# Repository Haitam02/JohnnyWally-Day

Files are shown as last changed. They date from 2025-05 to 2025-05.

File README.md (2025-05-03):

# 🤖 Eurobots 2025 – Embedded Systems Project

Welcome to the official repository for our participation in **Eurobots 2025**, part of the **Embedded Project** course.  
This project was developed by a team of six students:

- Ibrahim Zian  
- Samir Bouchrit  
- Haitam Lebatte  
- Soraya Jelti  
- Timothé Couturier  
- Yllke Prebreza  

---

## 🎮 Context: *The Show Must Go On*

This repository contains all the code used for the **Eurobots 2025** competition:  
**“The Show Must Go On”**

Each match lasts **100 seconds**.

- The **Big Robot** can start **immediately**. To score points, it must:
  - **Deploy a banner**
  - **Reach its final zone** before the match ends

- The **Pamis** and the **Superstar** can only start from the **85th second**.
  - The **Pamis** must move to one of the **three target zones** in front of the stage.
  - The **Superstar** must **climb the stage** and advance **as far as possible**.

- After 100 seconds, **all robots must stop** automatically.

---

## 🎯 Project Goal

The goal of the project was to design and build multiple coordinated robots with distinct behaviors to accomplish various game tasks.  
This work combines **embedded systems**, **low-level programming**, **robotic mechanics**, and **team-based technical project management**.

---

## 🗂️ Repository Structure

This repository is divided into several folders corresponding to each robot and its core functionality.  
Each contains a `README.md` with detailed explanations of its purpose and code.

- [`/Big_Robot's_Code/`](./Big_Robot's_Code/) – Readme for the big robot (movement, obstacle avoidance, decision-making).
- [`/Big_Robot's_Code-Banner_Deployment/`](./Big_Robot's_Code-Banner_Deployment/) – Readme for the banner deployment system.
- [`/Pami2's_Code/`](./Pami2's_Code/) – Readme of the "groupie" robots.
- [`/superstar/`](./superstar/) – Readme of the Superstar robot.
- [`/3Dpieces/`](./3Dpieces/) - Readme for 3D Printed Parts.

---

## 🧠 For Future Teams

This repository is also intended as a **resource for future teams** working on similar projects or competitions.  
You’ll find real-world examples of multi-robot coordination, real-time logic, and embedded software architecture.

---

Feel free to explore, learn, and build upon our work –  
**Good luck, and may the show go on!**

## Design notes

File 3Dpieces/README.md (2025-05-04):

# 3D Printable Parts – Robotics Project Components

This folder contains `.stl` files for 3D-printable components used in a robotics or embedded mechanical system. Each file corresponds to a specific part designed to be printed and assembled into larger submodules. Parts include supports for sensors, mechanical linkages, structural frames, and power supply mounts.

---

## 📄 File Overview

- `bas_pami.stl` – Base component for the PAMI  
- `haut_pami.stl` – Top part or cover for the PAMI  
- `IR_pami.stl` – Mount for infrared sensor for the PAMI  
- `IR_vertical_superstar.stl` – Vertical IR sensor support for the Superstar  
- `bas_superstar.stl` – Base platform for the Superstar  
- `bille_folle.stl` – Rolling ball support (for omnidirectional motion); adjusts height on metallic support  
- `support_2_US_superstar.stl` – Dual ultrasonic sensor mount for the Superstar  
- `support_pile_9V.stl` – 9V battery holder  
- `tige_servo.stl` – Rod or arm to be connected to a servo motor  
- `tirette_demarrage.stl` – Piece to keep both parts of the pull tab in correct position when closed  
- `US_Pami.stl` – Ultrasonic sensor holder for the PAMI module  
- `US_Robot.stl` – General ultrasonic sensor holder for the robot  
- `US_Robot_corner.stl` – Corner-mounted ultrasonic sensor holder for the robot  

---

## 🖨️ Printing Guidelines

- **Material:** PLA recommended for general use, PETG for higher durability  
- **Layer Height:** 0.2 mm  
- **Infill:** 20–40% (adjust based on strength requirements)  
- **Supports:** Some files (especially sensor mounts) may require support structures  

---

## 🔧 Assembly Instructions

- Clean all parts post-printing to remove residual support material.  
- Ensure tight fits; use M3 screws and brass inserts where applicable.  
- Parts such as `tige_servo.stl` and `tirette_demarrage.stl` interact with motors or mechanisms — verify motion clearance before final assembly.  
- Sensor holders (`IR_`, `US_`) should be oriented to maintain unobstructed field-of-view for reliable measurements.

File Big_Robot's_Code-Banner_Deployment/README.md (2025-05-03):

# Big Robot's Code - Banner Deployment

The banner deployment is an action that the Big Robot had to perform during its lifetime. However, it was designed independently so that work could be done in parallel on both the Big Robot and the deployment system without interference—aside from a few measurements taken.

This section will explain how to achieve the banner deployment from scratch, covering the following aspects:

- Components and Concept Explanation
- Wiring and Design
- Dependencies and Code Explanation

### *Components and Concept Explanation*

The necessary materials include:

- 2 x 9V batteries
- 1 x Arduino UNO
- 1 x PCA9685 (to control the servos via I2C)
- 1 x LM7805 (to regulate voltage and protect the PCA9685 from overvoltage)
- 13 x Servo motors
- 2 x Small hinges (to connect the hatch to the board)
- 3 x Pieces of fabric
- 3 x Light round bars and 3 x Heavy round bars

With all this material, the idea for the banner deployment is as follows:

After setting up the Arduino UNO, the LM7805, the PCA9685, and the 13 servos on the back of the board (with their arms extending outside to allow movement), and after setting up the hatch and wiring everything, we can proceed to place the light and heavy bars, paired with fabric in between.

The process is as follows:

1. The Big Robot sends a signal.
2. It receives the signal.
3. The hatch opens.
4. The light bar is released outside the field, deploying the fabric.
5. The hatch closes.
6. The heavy bar is released inside the field, counterbalancing the fabric.
7. The Big Robot moves forward to ensure no gap between the fabrics.
8. The cycle repeats.

After performing this three times, the banner is fully deployed, and the Big Robot can continue its journey.

### *Wiring and Design*

For a better understanding of the wiring and design, it is recommended to refer to the visual schematic:

#### Wiring Schematic
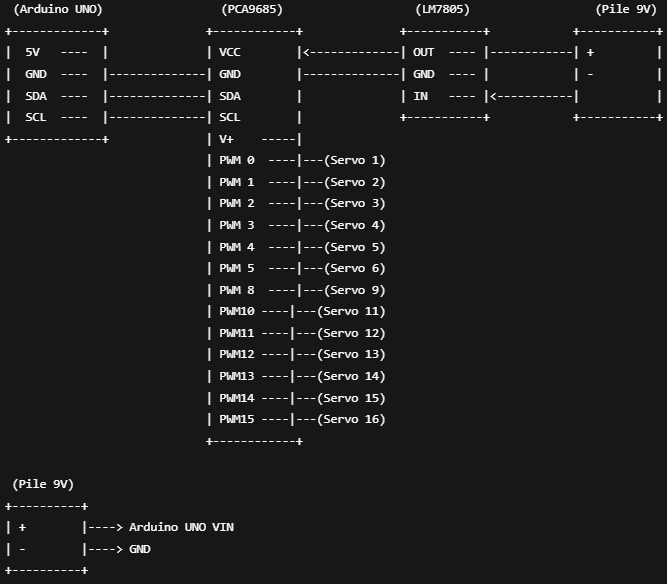
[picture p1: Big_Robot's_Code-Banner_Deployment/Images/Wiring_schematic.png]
Wiring schematic


#### Board Design Schematic (Back of the Board)
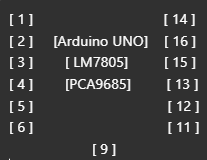
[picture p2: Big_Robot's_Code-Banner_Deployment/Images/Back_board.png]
Back board


#### Board Design Photo (Front of the Board)
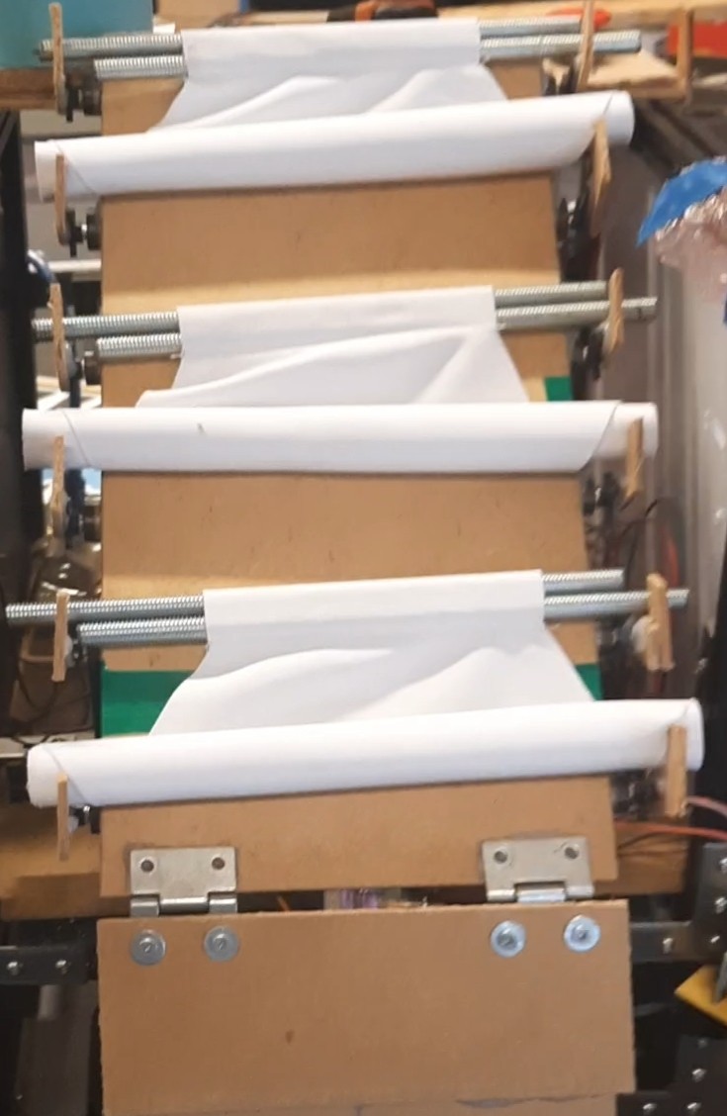
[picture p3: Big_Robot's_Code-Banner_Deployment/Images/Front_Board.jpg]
Front board


### *Dependencies and Code Explanation*

For the dependencies, the following libraries are required:

- Adafruit PWM Servo Driver Library
- Wire Library (included with Arduino)
- ArduinoLog.h

Regarding the code organization, the project has been structured into three modular files for better maintainability and clarity:

- servo_controller.h - Contains all constant definitions, pin declarations, and function prototypes

- servo_controller.cpp - Implements all servo control logic and sequence functions

- main.ino - Handles the primary program flow and signal processing

The code is well-commented to explain the function of each part in detail, but here's an overall summary for better understanding.

At the beginning (as shown in the wiring schematic), I define the servo channels based on where I connected them. In the `setupServoController()` function (in servo_controller.cpp), I set initial positions to reset the servo arms so that the bars can be placed on top of them.

In the `loop()` function (in main.ino), I address an issue where the Big Robot's reset sends a "false" signal to my receiving pin (pin 2) due to the reset pulse. To solve this, I ignore any signals sent during the first few moments. After this delay, I call `runPart1`, `runPart2`, and then `runPart3`, one after the other, after receiving each signal.

The logic is as follows:

- `runPart1` releases the first part by lowering the servos that hold it

- `runPart2` raises the servos from the previous part to lower the fabric one level and then drop it, as in `runPart1`

- `runPart3` raises the servos from `runPart2` to lower the fabric one more level and let it drop again

This process allows the sequential deployment of the banner as described.

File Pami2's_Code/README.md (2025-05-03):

# PAMI's code
We used 2 pami with a similar code. Both use a rope, two ultrasound sensors to detect obstacles and two infrared to follow the lines. This is how they got to the playground.

The code works with a FSM containing the states START, GO, STOP, BACK, LEFT, RIGHT and OBSTACLE_DETECTED. 
The code starts (state START) when the rope is open (state high). The PAMI starts only when the first delay is reached (85 seconds min rule) and stops once the second delay (its end-of-life delay) is reached. At this point, the FSM is in the STOP state and it’s the end of the code. For the PAMI to reach their right zone, each has an adjusted speed and end-of-life delay.

The differences between the two codes are the initial position of the servo motor. The PAMI number 2 has its servo initialized with ```const int positionInitiale = -15;```. This is due to its placement in the starting zone, placing the servomotor like this allow to not disturb the superstar. The speed and life-time delay are also different depending on the PAMI. These are parameters that we used to adjust the position of the PAMIs into the final area.

### Requirements
To use the code, you will need all the libraries listed below:
- Wire.h
- Adafruit_MotorShield.h           
- SoftwareSerial.h 
- Servo.h 
- NewPing.h
- ArduinoLog.h

### Pin used
#### List of the pin for the PAMI 2 & 3
| Sensors | Side  |Pin | Pin |
|---|---|---|---|
|Ultrasound | Left  |Trg-12|Echo-13|
|Ultrasound | Right |Trg-8 |Echo-9 |
|Infrared | Left  | 5  | / |
|Infrared | Right | 4  | / |
|Rope| /|  11|/|
|Servomotor|/|6|/|
|Encoder|Left|2 |/|
|Encoder| Right| 3|/|

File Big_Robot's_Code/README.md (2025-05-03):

# 🤖 Documentation: Grand Robot Code

## 1. Introduction

This system controls an autonomous robot equipped with:
- DC motors with encoders for precise movement.
- Ultrasonic sensors to detect and avoid obstacles.
- A PID algorithm to correct trajectory errors in real time.
- Programmable sequences (startup, final movement).
- Signal sending for banner deployment.

🎯 **Goal**: Ensure precise movement over a defined distance, detect obstacles, and trigger a banner deployment.  
This system was tested on an Arduino Mega board, which communicated with **two additional Arduino Uno boards**:
- The **first Uno** managed all ultrasonic sensors and sent a HIGH signal to the Mega when an obstacle was detected.
- The **second Uno** handled the banner deployment, waiting for a signal from the Mega to activate it.

**Context**: This robot is designed to participate in the **Eurobots 2025** tournament. The code is therefore adapted to the layout and rules of that competition.

---

## 2. 📚 Required Libraries

### 1. Core Libraries

| Library | Source / Installation | Role |
|---|---|---|
| Adafruit_MotorShield | Available via Arduino IDE | Controls the motors via Adafruit motor shield  |
| ArduinoLog | [GitHub](https://github.com/thijse/Arduino-Log.git)| Serial logging and debug output |
| NewPing | Available via Arduino IDE | Handles ultrasonic sensors (e.g. HC-SR04) |
| LiquidCrystal_I2C | Available via Arduino IDE | LCD display via I2C |

### 2. Dependencies (Auto-installed)

| Library | Role |
|---|---|
| Wire | I2C communication (bundled with Arduino) |
| Arduino.h  | Core Arduino definitions (always included) |

---

## 3. 🗂️ Code Structure

### Main Files

| File | Role |
|---|---|
| `main.ino` | Main loop, manages sequences and timing |
| `pid_control.cpp`  | PID algorithm implementation for motor distance correction |
| `motor_control.cpp`| Motor driving logic (speed, direction) + `Stop()` function |
| `encoder.cpp` | Encoder pulse reading for distance estimation |
| `signal.cpp` | Obstacle detection (`sensorMesure()`) and external signaling |
| `constants.h` | Pin assignments (encoders, signals, sensors, etc.) |
| `globals.h` | Global variables (PID values, speeds, constants) |

---

## 4. ⚙️ Key Features

We'll go through each file to better understand how the system works. This will help you customize the logic to suit your own project. Relevant code snippets are included to illustrate key concepts.

---

### 1️⃣ `pid_control.cpp`

This file is critical. It ensures that the speed difference between both wheels is regulated using a PID controller by passing a **target distance** to the `pid()` function.

---

#### 🔧 Core Mechanism

1. **Initialization**  
   Reset encoder counters:
   ```cpp
   posi1 = 0;
   posi2 = 0;
   ```

2. **Control Loop**  
   Run while the traveled distance is less than the target:
   ```cpp
   while (abs(currentDistance) <= abs(target)) {
     ...
   }
   ```

3. **Calculations**
   - Traveled distance:
     ```cpp
     currentDistance = (posi / stepsPerRevolution) * wheelCircumference;
     ```
   - Error calculation:
     ```cpp
     error = target - currentDistance;
     ```

4. **PID Correction**  
   Apply gains using:
   ```cpp
   updateMotorPID(motor, error, kp, ki, kd, maxspeed);
   ```

> The `updateMotorPID()` function is defined in `motor_control.cpp`.

---

#### ⚙️ Motor Synchronization

```cpp
if (abs(error1 - error2) > 0) {
  adjustedSpeed1 = (error1 > error2) ? maxspeed * 0.8 : maxspeed * 0.9;
  adjustedSpeed2 = (error1 > error2) ? maxspeed * 0.9 : maxspeed * 0.85;
}
```

- If one motor is slower, it gets a speed boost to synchronize movement.

---

#### 🛑 Obstacle Handling

```cpp
if (sensorMesure()) {
  Stop();
  delay(6000);  // Safety delay
}
```

> The logic is straightforward but customizable. You may implement alternative reactions to obstacles instead of simply stopping.

---

#### 📊 PID Flow Diagram

```mermaid
graph TD
  A[Target] --> B[Calculate Error]
  B --> C[PID Correction]
  C --> D[Adjust Motor Speeds]
  D --> E{Target Reached?}
  E -->|No| B
  E -->|Yes| F[Stop Motors]
```

---

### 2️⃣ `motor_control.cpp`

This file contains the configuration and control logic for both DC motors.

---

#### ⚙️ 1. Motor Initialization

```cpp
Adafruit_MotorShield AFMS = Adafruit_MotorShield();
Adafruit_DCMotor *myMotor1 = AFMS.getMotor(1); // Motor 1 on port M1
Adafruit_DCMotor *myMotor2 = AFMS.getMotor(2); // Motor 2 on port M2
```

- `AFMS`: Communication object for the Adafruit motor shield.
- `myMotor1` / `myMotor2`: Pointers to each motor object.

---

#### 🔧 2. Core Functions

---

##### 🛑 A. Stop Motors – `Stop()`

```cpp
void Stop() {
  myMotor1->run(RELEASE);
  myMotor2->run(RELEASE);
}
```

- **Action**: Disables both motors by releasing them.
- **Usage**: Used in emergency stops or when completing a movement.

---

##### ↩️ B. Rotate Robot – `rotate()`

```cpp
void rotate(int durationMs, bool toLeft) {
  if (toLeft) {
    myMotor1->run(BACKWARD); // Left motor backward
    myMotor2->run(FORWARD);  // Right motor forward
  } else {
    myMotor1->run(FORWARD);  // Left motor forward
    myMotor2->run(BACKWARD); // Right motor backward
  }
  delay(durationMs);
  Stop();
  posi1 = posi2 = 0; // Reset encoder counts
}
```

- `durationMs`: Duration of the rotation (in ms).
- `toLeft`: `true` to rotate left, `false` to rotate right.
- **Effect**: Spins the robot on the spot.

---

##### 🧠 C. PID Motor Control – `updateMotorPID()`

```cpp
void updateMotorPID(Adafruit_DCMotor *motor, float error, float kp, float ki, float kd, float maxspeed) {
  static float integral = 0.0;
  static float lastError = 0.0;
  
  integral += error;
  float derivative = error - lastError;
  float output = kp * error + ki * integral + kd * derivative;
  motor->setSpeed(constrain(abs(output), 0, maxspeed));
  lastError = error;
}
```

- `error`: Distance to target.
- `kp`, `ki`, `kd`: PID coefficients.
- `maxspeed`: Speed limit (0–255).
- **Purpose**: Smoothly adjust the motor speed using PID feedback, as taught in control theory.

---

#### 🧪 3. Example Usage

```cpp
// Rotate left for 1 second
rotate(1000, true);

// Apply PID to motor 1 (error = 2.5 cm, max speed = 200)
updateMotorPID(myMotor1, 2.5, 80.0, 10.0, 1.0, 200);
```

---

### 3️⃣ `encoder.cpp`

This file handles **encoder readings** to measure the **position and speed** of the motors in real-time.

---

#### 🧾 1. Global Variables

```cpp
volatile int posi1 = 0; // Step count for Motor 1
volatile int posi2 = 0; // Step count for Motor 2
```

- `volatile`: Indicates that the variable can be changed inside an **Interrupt Service Routine (ISR)**.
- **Purpose**: Keeps track of the number of steps each encoder has detected since reset.

---

#### ⚡ 2. Interrupt Service Routines (ISRs)

**For Motor 1:**

```cpp
void readEncoder1() {
  int b = digitalRead(ENCB1);
  posi1 += (b > 0) ? 1 : -1;
}
```

**For Motor 2:**

```cpp
void readEncoder2() {
  int c = digitalRead(ENCB2);
  posi2 += (c > 0) ? 1 : -1;
}
```

---

#### ⚙️ How It Works

1. Each ISR reads the state of the second encoder pin (ENCB).
2. Based on that state, the function increments or decrements the position counter (`posi1` or `posi2`).

> 📌 The encoder pins (`ENCA1`, `ENCB1`, `ENCA2`, `ENCB2`) are defined in `constants.h`.

---

### 4️⃣ `signal.cpp`

This file manages **obstacle detection** and **external communication** between the robot and other Arduino boards (such as the one controlling the banner).

---

#### ⚙️ 1. Global Configuration

```cpp
bool ultrasonicsActive = true;  // Master switch for obstacle detection
```

- **Role**: Enables or disables ultrasonic detection globally.
- **Default value**: `true` (detection enabled).

---

#### 📤 2A. Sending a Signal – `sendSignal()`

```cpp
void sendSignal() {
  digitalWrite(SIGNAL_PIN2, HIGH);  // Send signal
  delay(50);                        // 50 ms pulse
  digitalWrite(SIGNAL_PIN2, LOW);   // End pulse
  delay(10000);                     // Wait 10 seconds
}
```

- Sends a **50 ms pulse** on `SIGNAL_PIN2` to notify the **banner-deploying Arduino**.
- Waits **10 seconds** to allow the banner to fully deploy.
- Pin definitions are found in `constants.h`.

---

#### 🧭 2B. Obstacle Detection – `sensorMesure()`

```cpp
bool sensorMesure() {
  if (!ultrasonicsActive) return false;

  if (digitalRead(SIGNAL_PIN) == HIGH) {
    return true;  // Obstacle detected
  }
  return false;   // No obstacle
}
```

- **Logic**:
  - Reads the digital state of `SIGNAL_PIN`.
  - A separate Arduino (with ultrasonic sensors) sends a `HIGH` signal when an obstacle is detected.

> 📌 `SIGNAL_PIN` and `SIGNAL_PIN2` are both defined in `constants.h`.

---

### 5️⃣ `sequence.cpp`

This file orchestrates the robot’s **autonomous movements** depending on the starting zone (blue or orange).

---

#### 🧩 1. Global Structure

```cpp
extern LiquidCrystal_I2C lcd;       // LCD screen access
extern bool ultrasonicsActive;      // Obstacle detection control
```

- These are **external variables**, shared from other modules.
- `lcd`: Used to display information (like score).
- `ultrasonicsActive`: Controls whether sensors are enabled during the sequence.

---

#### 🧠 2. Main Function: `executeInitialSequence()`

```cpp
void executeInitialSequence(bool isBlueZone)
```

- `isBlueZone`: `true` if the robot starts in the blue zone, `false` for the orange zone.

---

#### 🔁 Sequence Logic

1. **Initialization**:
   - Temporarily disables ultrasonic sensors:
     ```cpp
     ultrasonicsActive = false;
     ```
   - Displays a fixed score (for example purposes):
     ```cpp
     lcd.print("Score : 20");
     ```

2. **Motion Sequence**:
   - Move forward/backward depending on the zone:
     ```cpp
     pid(isBlueZone ? 14.0 : -14.0);
     ```
   - Rotate with a zone-specific duration:
     ```cpp
     rotate(isBlueZone ? 1100 : 1350, true);
     ```

3. **Banner Signal**:
   - Trigger three signals to deploy the banner:
     ```cpp
     sendSignal();
     sendSignal();
     sendSignal();
     ```

---

#### 🛠️ Customize Your Sequence

You can design your own movement routine by combining:
- `pid(distance)` – forward/backward movement.
- `rotate(duration, direction)` – turning left/right.
- `sendSignal()` – banner deployment or external communication.

---

### 6️⃣ `globals.cpp`

This file acts as a **central hub** for all configurable parameters in the system. It allows for easy tuning of the robot's behavior.

---

#### 🎚️ 1. PID Parameters

```cpp
// Motor 1
float kp1 = 80.0;  // Proportional gain
float ki1 = 10.0;  // Integral gain
float kd1 = 1.0;   // Derivative gain

// Motor 2
float kp2 = 80.0;
float ki2 = 10.0;
float kd2 = 1.0;
```

- These values define the **PID control behavior** of each motor.
- The current values are standard defaults, but you should **tune them experimentally** for your own robot.

---

#### 🚀 2. Maximum Speed

```cpp
float maxspeed = 130;  // Range: 0–255
```

- Limits the PWM speed output to motors.
- Used to cap the robot’s top speed for better control.

---

#### 🧮 3. Physical Constants

```cpp
extern const float stepsPerRevolution = 1400.0;  // Encoder steps per wheel revolution
extern const float wheelDiameter = 6.8;          // Wheel diameter in cm
extern const float wheelCircumference = PI * wheelDiameter;
```

These constants are used to **translate encoder steps into real-world distance**.

🛠️ **Calibration steps**:
1. Measure the actual diameter of your wheels.
2. Count how many steps your encoder produces for a full wheel rotation.

---

### 7️⃣ `constants.cpp`

This header file serves as a **central reference** for all hardware-related constants, especially **pin assignments**.

---

#### 🧷 Encoder Pins

```cpp
#define ENCA1 2   // Encoder A for Motor 1
#define ENCB1 3   // Encoder B for Motor 1
#define ENCA2 19  // Encoder A for Motor 2
#define ENCB2 18  // Encoder B for Motor 2
```

- These pins must match your hardware wiring.
- They are used by the encoder interrupt routines to measure wheel rotation.

---

#### 🔁 Zone Selection Switch

```cpp
#define SWITCH_PIN 8  // Limit switch
```

- Used to **select the starting zone** (blue or orange) before the match begins.
- Read in `main.ino` to determine the correct sequence.

---

#### 📡 Signal Pins

```cpp
#define SIGNAL_PIN 7     // Input: Obstacle detection signal
#define SIGNAL_PIN2 13   // Output: Banner trigger signal
```

- `SIGNAL_PIN`: Receives `HIGH` from the **ultrasonic Arduino** when an obstacle is detected.
- `SIGNAL_PIN2`: Sends `HIGH` to the **banner-deploying Arduino** to trigger deployment.

---

### 8️⃣ `main.ino`

This is the **main control file** that ties all modules together. It handles initialization, timing, and controls the overall sequence of execution.

---

#### 🏗️ 1. System Initialization

---

##### 🔌 A. `setup()` – Hardware and Peripheral Configuration

```cpp
void setup() {
  // Serial and logging initialization
  Serial.begin(9600);
  Log.begin(LOG_LEVEL_VERBOSE, &Serial);

  // Pin configuration
  pinMode(ENCA1, INPUT);               // Encoder pin
  pinMode(REED_PIN, INPUT_PULLUP);     // Start pull switch

  // LCD and motor shield
  lcd.init();
  AFMS.begin();

  // Encoder interrupts
  attachInterrupt(digitalPinToInterrupt(ENCA1), readEncoder1, RISING);
}
```

- Logging is set to `VERBOSE` for debug output.
- Encoder interrupts are essential for accurate motion tracking.

---

##### 📦 B. Global Variables

```cpp
bool start = false;                         // Start flag
unsigned long startTime;                   // Timer
LiquidCrystal_I2C lcd(0x27, 16, 2);        // LCD display
```

- `start` is used to mark when the match begins and trigger the timer.

---

#### 🔁 2. Main Logic Loop – `loop()`

---

##### 🎯 A. Start Detection via Reed Switch

```cpp
int proximity = digitalRead(REED_PIN);  // Check if magnet is present

if (proximity == LOW) {
  Log.notice("Magnet detected. Waiting...");
} else {
  if (!start) {
    startTime = millis();  // Start the timer
    start = true;
  }
}
```

- Activated by removing a **magnet pull switch** (REED sensor).
- Triggers the beginning of the autonomous logic.

---

##### 🧠 B. Sequence Execution

```cpp
if (!initialSequenceCompleted) {
  executeInitialSequence(switchState == LOW);
  initialSequenceCompleted = true;
}

if (!endSequenceExecuted && millis() - startTime >= 95000) {
  pid(60); // Final movement
  endSequenceExecuted = true;
}
```

- Two main phases:
  1. **Initial sequence**: Executed once at match start.
  2. **Final sequence**: Executed after 95 seconds, e.g., to enter the parking zone.

---

#### 🖼️ Execution Flow Diagram

```mermaid
graph TD
  A[Start] --> B{Reed switch activated?}
  B -->|No| C[Start timer]
  C --> D[Execute initial sequence]
  D --> E{95s elapsed?}
  E -->|Yes| F[PID for 60cm]
  E -->|No| G[Stop motors]
```

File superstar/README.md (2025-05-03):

# Superstar Robot

## Overview

Superstar is a line-following robot with obstacle detection capabilities. The robot follows a line on the ground using IR sensors and can detect obstacles in its path using an ultrasonic sensor. It also includes a servo motor for auxiliary movements.

## Features

- Line following using dual IR sensors
- Obstacle detection and avoidance
- State-based behavior control system
- Servo motor for additional movements
- Comprehensive logging system using ArduinoLog library

## Hardware Requirements

- Arduino board
- Adafruit Motor Shield V2
- 2 DC motors (connected to M1 and M2 on the shield)
- Ultrasonic sensor (HC-SR04)
- 2 IR line detection sensors
- Servo motor
- Power supply

## Pin Configuration

### Motors

| Component | Connection | Description |
| --- | --- | --- |
| Left Motor  | M1 on Motor Shield | Controls left wheel movement  |
| Right Motor | M2 on Motor Shield | Controls right wheel movement |

### Sensors

| Sensor | Pin | Description |
| --- | --- | --- |
| Ultrasonic Trigger | 9 | Sends trigger signal to HC-SR04 |
| Ultrasonic Echo | 10  | Receives echo signal from HC-SR04  |
| Left IR Sensor | 8 | Detects line on the left side |
| Right IR Sensor | 7 | Detects line on the right side |
| Servo Motor | 9 | Controls auxiliary servo movements |

### Operation Modes

The robot operates in three states:

1. **RUN**: Normal line following mode, follows a line and checks for obstacles
2. **STOP**: Temporary halt when an obstacle is detected (stops for 1 second)
3. **DANCE**: Special mode where the robot stops and the servo performs a sweeping motion

## Software Architecture

The software is organized into several modules:

- `Motor`: Controls robot movement (forward, turning, stopping)
- `Sensor`: Handles line detection and obstacle detection
- `ServoControl`: Controls servo motor movements
- `Superstar`: Main controller that coordinates the robot's behavior

## Logging System

The robot uses the ArduinoLog library to provide detailed operational logs. The logs are formatted with different levels to help with debugging and monitoring:

- **VERBOSE**: Detailed information for debugging, includes sensor readings and motor actions
- **NOTICE**: Normal but significant events like state changes and initializations
- **WARNING**: Important events like obstacle detection
- **ERROR**: Critical issues that may require intervention

To view the logs:

1. Connect the Arduino to your computer
2. Open the Serial Monitor in the Arduino IDE
3. Set the baud rate to 115200
4. Power on the robot

The logs provide real-time information about what the robot is doing, helping you diagnose issues and understand the robot's behavior.

## Usage

1. Install the ArduinoLog library (Sketch > Include Library > Manage Libraries)
2. Upload the code to your Arduino board
3. Connect to the Serial monitor (115200 baud) to view logs
4. Place the robot on a line
5. Power on the robot
6. The robot will automatically follow the line and avoid obstacles for 15 seconds before stopping

## Library Dependencies

- Wire.h
- Adafruit_MotorShield.h
- ArduinoLog.h
- NewPing.h
- Servo.h

## Project Structure

```
superstar/
├── superstar.ino      # Main Arduino sketch
├── superstar.h        # Main controller class header
├── superstar.cpp      # Main controller class implementation
├── motor.h            # Motor control header
├── motor.cpp          # Motor control implementation
├── sensor.h           # Sensor interface header
├── sensor.cpp         # Sensor interface implementation
├── servoControl.h     # Servo controller header
├── servoControl.cpp   # Servo controller implementation
└── README.md          # This file
```

## Notes

- The robot runs for 15 seconds after power-up, then automatically stops
- The obstacle detection range is set to 20cm by default
- The line following sensors are expected to return HIGH (1) when they detect a line
- All String constants use F() macro to save RAM by storing strings in flash memory
- The CR macro in the logs ensures proper line endings in the Serial monitor

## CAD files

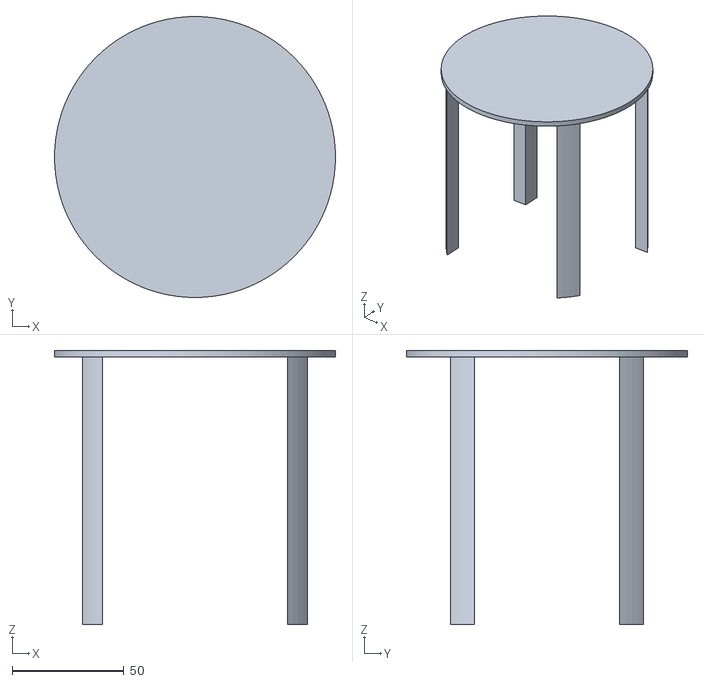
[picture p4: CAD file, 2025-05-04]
3Dpieces/haut_pami.stl
126.0 x 126.0 x 123.0

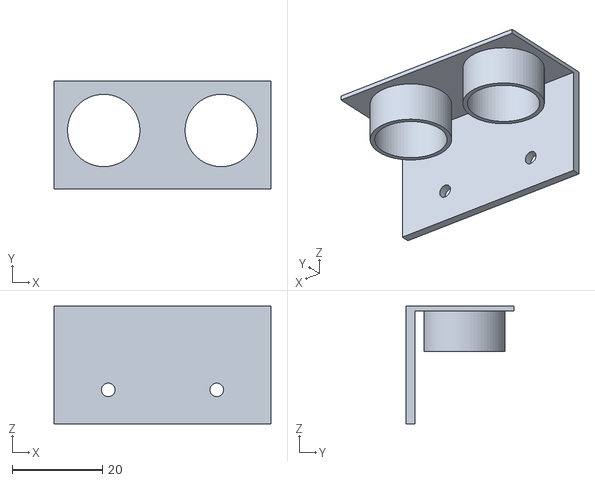
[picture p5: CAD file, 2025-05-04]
3Dpieces/US_Robot.stl
48.0 x 24.0 x 26.0

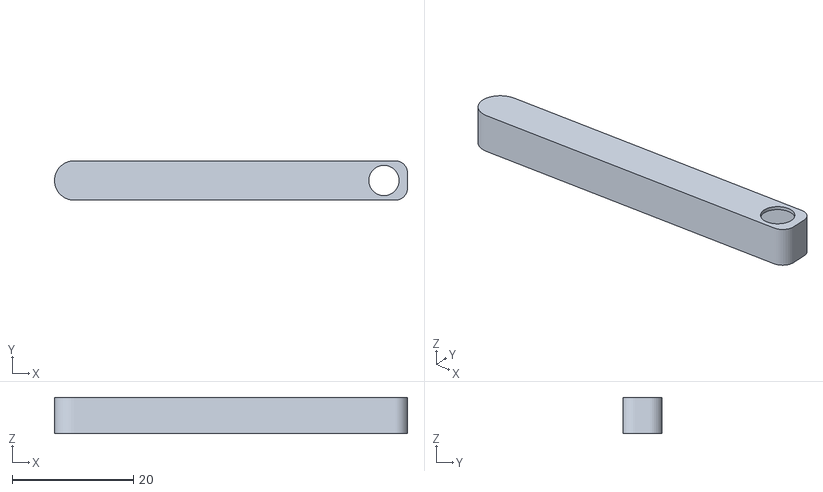
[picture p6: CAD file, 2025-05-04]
3Dpieces/tige_servo.stl
58.2 x 6.50 x 6.00

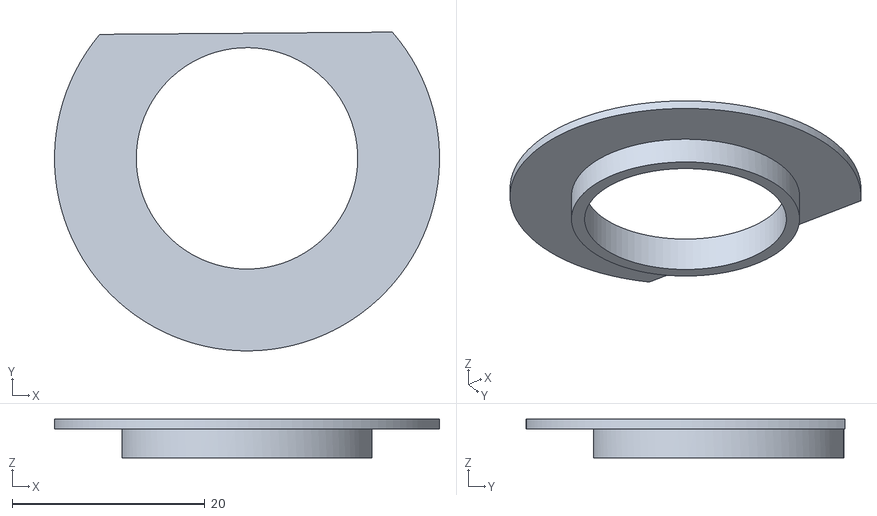
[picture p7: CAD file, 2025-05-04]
3Dpieces/bille_folle.stl
40.0 x 33.1 x 4.00

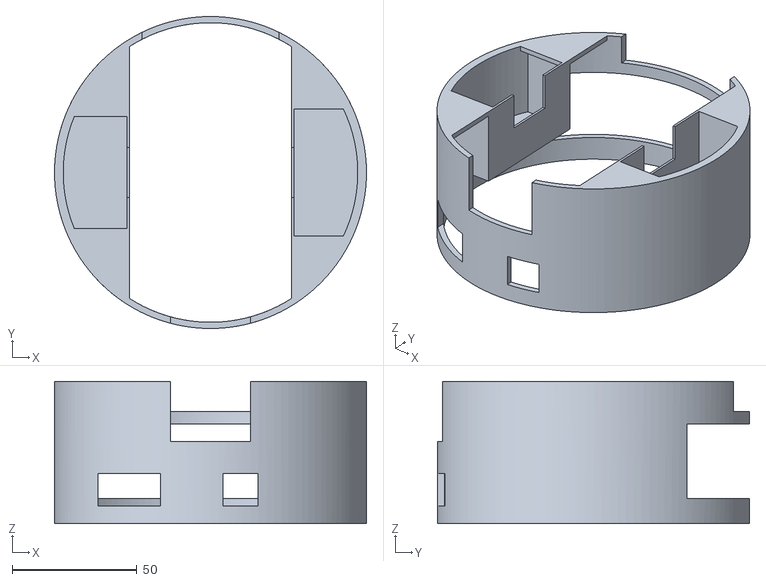
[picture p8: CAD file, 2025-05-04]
3Dpieces/bas_pami.stl
125.0 x 125.0 x 57.0

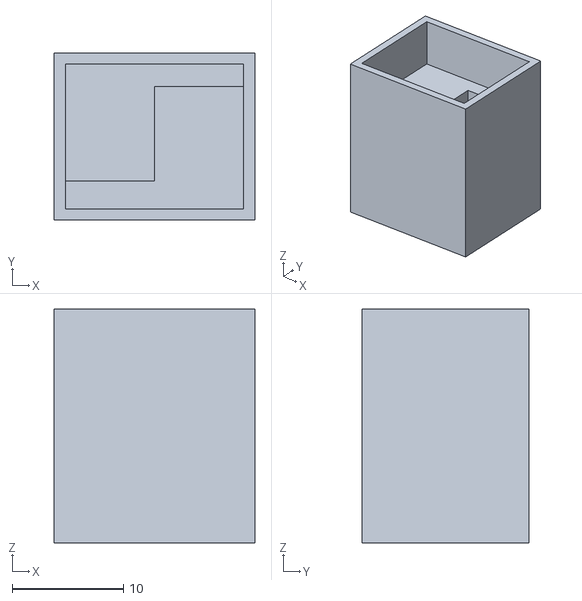
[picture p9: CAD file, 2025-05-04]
3Dpieces/tirette_demarrage.stl
18.0 x 15.0 x 21.0

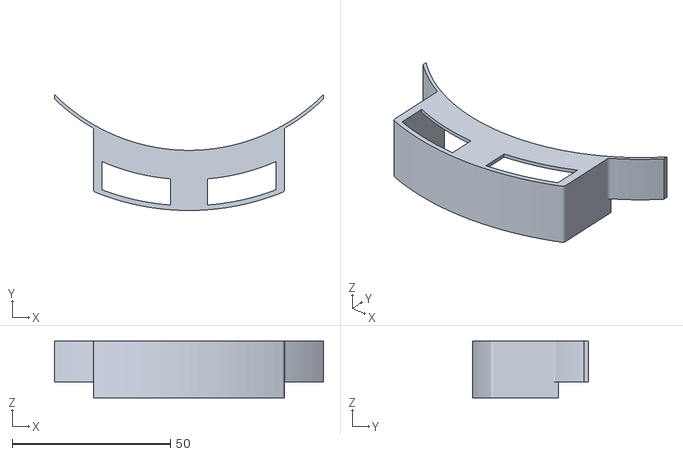
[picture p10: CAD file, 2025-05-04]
3Dpieces/IR_pami.stl
85.0 x 36.6 x 18.0

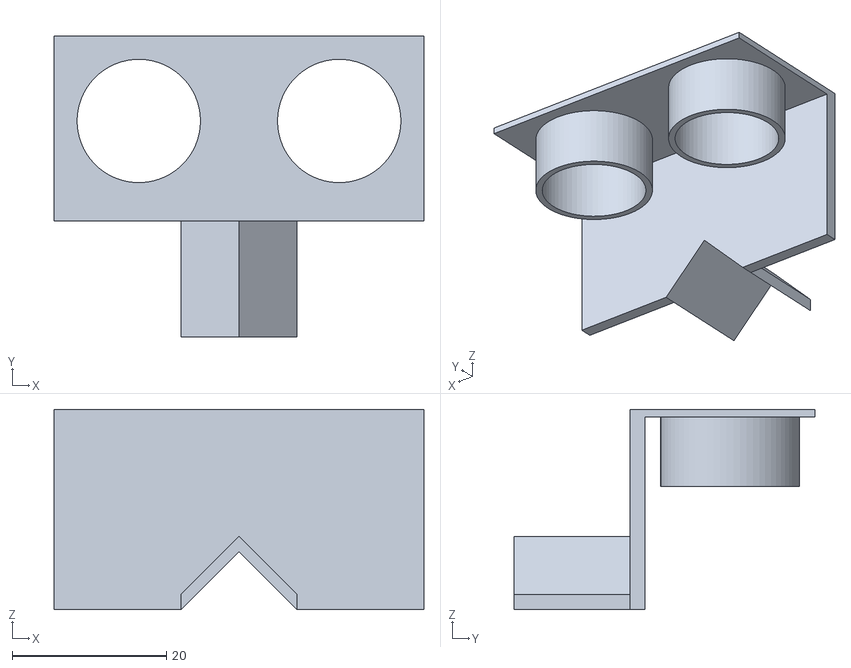
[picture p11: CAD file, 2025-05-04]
3Dpieces/US_Robot_corner.stl
48.0 x 39.0 x 26.0

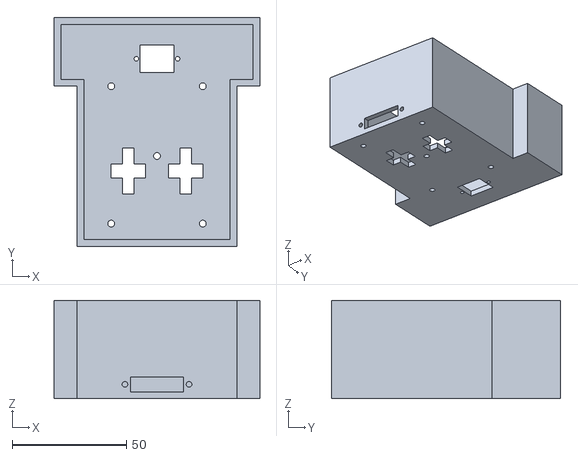
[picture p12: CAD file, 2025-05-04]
3Dpieces/bas_superstar.stl
90.0 x 100.0 x 43.0

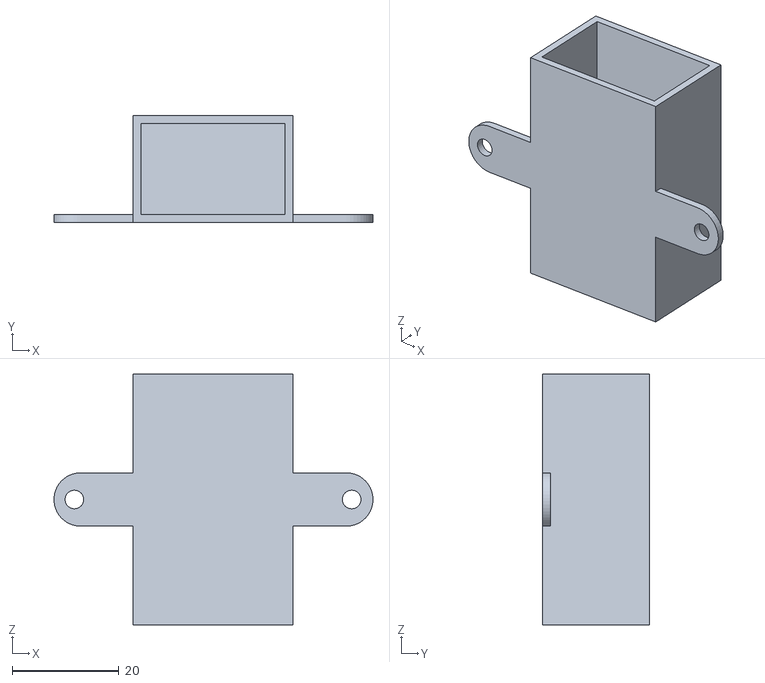
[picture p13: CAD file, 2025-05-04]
3Dpieces/support_pile_9V.stl
59.8 x 20.0 x 47.0

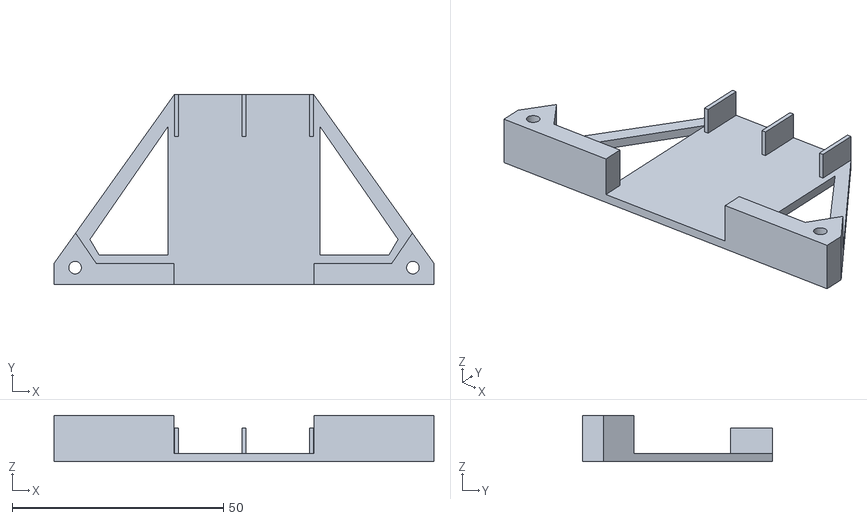
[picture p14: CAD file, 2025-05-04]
3Dpieces/IR_vertical_superstar.stl
90.0 x 45.0 x 11.0

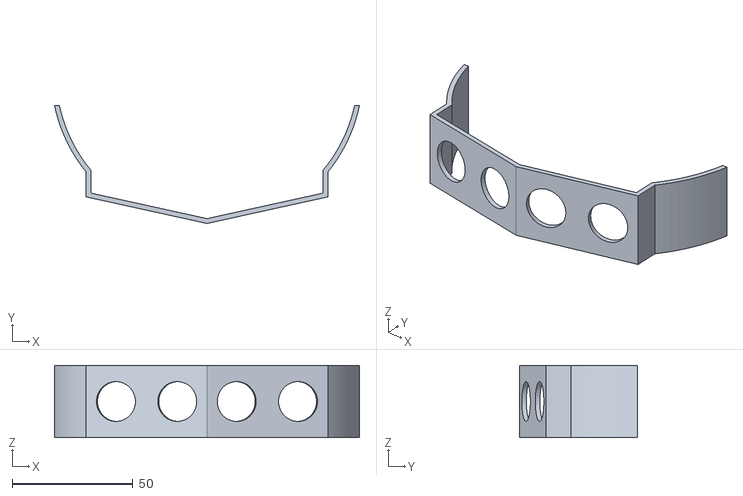
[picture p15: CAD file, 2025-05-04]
3Dpieces/US_Pami.stl
126.3 x 48.8 x 30.0

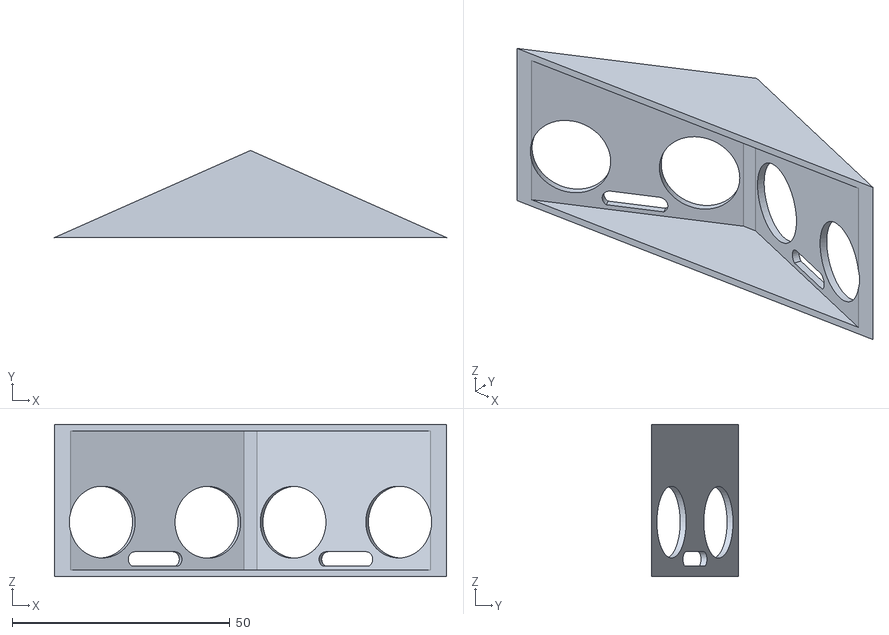
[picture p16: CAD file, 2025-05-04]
3Dpieces/support_2_US_superstar.stl
90.0 x 20.0 x 35.0

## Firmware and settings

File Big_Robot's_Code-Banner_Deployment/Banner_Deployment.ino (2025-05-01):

#include <Wire.h>
#include <Adafruit_PWMServoDriver.h>

Adafruit_PWMServoDriver pwm = Adafruit_PWMServoDriver();

// Servo channel definitions (PWM controller channels)
// Note: Channels are numbered to match physical board numbering (1-16)
// but use 0-15 addressing for the PWM controller
#define SERVO1 0   // Physical servo 1
#define SERVO2 1   // Physical servo 2
#define SERVO3 2   // Physical servo 3
#define SERVO4 3   // Physical servo 4
#define SERVO5 4   // Physical servo 5
#define SERVO6 5   // Physical servo 6
#define SERVO9 8   // Physical servo 9 
#define SERVO11 10 // Physical servo 11
#define SERVO12 11 // Physical servo 12
#define SERVO13 12 // Physical servo 13
#define SERVO14 13 // Physical servo 14
#define SERVO15 14 // Physical servo 15
#define SERVO16 15 // Physical servo 16

// Servo pulse width limits (in microseconds)
#define SERVOMIN 150 // Minimum pulse length
#define SERVOMAX 600 // Maximum pulse length

// Signal pin from main robot controller
#define SIGNAL_PIN 2  // Interrupt pin for receiving signals

// Signal detection variables
volatile int signalCount = 0;       // Counts received signals (currently not used)
unsigned long lastTrigger = 0;      // Last signal detection time (for debouncing)

// System state variables
int currentState = 0;     // 0 = idle, 1 = part 1, 2 = part 2, 3 = part 3
bool lastSignal = LOW;    // Previous signal state (for edge detection)

void setup() {
  // Initialize I2C communication
  Wire.begin();
  
  // Initialize PWM controller
  pwm.begin();
  pwm.setPWMFreq(60); // Set PWM frequency to 60Hz
  
  // Start serial communication for debugging
  Serial.begin(9600);

  // Configure signal pin and interrupt
  pinMode(SIGNAL_PIN, INPUT);
  attachInterrupt(digitalPinToInterrupt(SIGNAL_PIN), onSignalReceived, RISING);

  // Set initial servo positions
  setServoAngle(SERVO1, 120);
  setServoAngle(SERVO2, 120);
  setServoAngle(SERVO3, 120);
  setServoAngle(SERVO4, 120);
  setServoAngle(SERVO5, 0);
  setServoAngle(SERVO6, 50);
  setServoAngle(SERVO9, 100);
  setServoAngle(SERVO11, 125);
  setServoAngle(SERVO12, 125);
  setServoAngle(SERVO13, 75);
  setServoAngle(SERVO14, 75);
  setServoAngle(SERVO15, 75);
  setServoAngle(SERVO16, 75);
}

// Signal processing variables
unsigned long lastSignalTime = 0;    // Last valid signal reception time
bool signalReceived = false;         // Signal received flag
const unsigned long resetDelay = 5000; // 5 second reset delay after sequence

void loop() {
  bool signal = digitalRead(SIGNAL_PIN);

  // Ignore signals during reset period (5 seconds after last signal)
  if (millis() - lastSignalTime < resetDelay) {
    return; // Wait during reset period
  }

  // Detect rising edge (LOW -> HIGH transition)
  if (signal == HIGH && lastSignal == LOW) {
    lastSignalTime = millis(); // Update last signal time
    currentState++; // Advance to next state
    Serial.print("Signal received. Transitioning to state ");
    Serial.println(currentState);

    delay(1000); // Small debounce delay

    // Execute appropriate sequence based on current state
    if (currentState == 1) {
      delay(1000); // Initial delay before starting
    } else if (currentState == 2) {
      runPart1(); // Execute part 1 sequence
    } else if (currentState == 3) {
      runPart2(); // Execute part 2 sequence
    } else if (currentState == 4) {
      runPart3(); // Execute part 3 sequence
      while (true); // Stop program after final sequence
    }
  }

  // Update previous signal state
  lastSignal = signal;
}

/**
 * Interrupt service routine for signal detection
 * Implements basic debouncing (500ms)
 */
void onSignalReceived() {
  unsigned long now = millis();
  if (now - lastTrigger > 500) { // Debounce check
    signalCount++;
    lastTrigger = now;
  }
}

/**
 * Sequence for part 1 of banner deployment
 * Controls servos 5,6,9,11,12
 */
void runPart1() {
  setServoAngle(SERVO9, 10);
  delay(5000);
  setServoAngle(SERVO11, 0);
  setServoAngle(SERVO6, 180);
  delay(1000);
  setServoAngle(SERVO9, 100);
  delay(200);
  setServoAngle(SERVO12, 0);
  setServoAngle(SERVO5, 180);
  delay(5000);
}

/**
 * Sequence for part 2 of banner deployment
 * Controls servos 3,4,5,6,9,11,12,13,15
 */
void runPart2() {
  setServoAngle(SERVO9, 10);
  delay(100);
  setServoAngle(SERVO13, 0);
  setServoAngle(SERVO4, 180);
  delay(1000);
  setServoAngle(SERVO13, 125);
  setServoAngle(SERVO4, 50);
  setServoAngle(SERVO12, 125);
  setServoAngle(SERVO5, 50);
  setServoAngle(SERVO11, 125);
  setServoAngle(SERVO6, 50);
  setServoAngle(SERVO9, 100);
  delay(500);
  setServoAngle(SERVO15, 0);
  setServoAngle(SERVO3, 170);
  delay(500);
  setServoAngle(SERVO13, 0);
  setServoAngle(SERVO4, 180);
  delay(500);
  setServoAngle(SERVO12, 0);
  setServoAngle(SERVO5, 180);
  delay(500);
  setServoAngle(SERVO11, 0);
  setServoAngle(SERVO6, 180);
  delay(5000);
}

/**
 * Sequence for part 3 of banner deployment (final sequence)
 * Controls servos 1,2,3,4,9,13,14,15,16
 */
void runPart3() {
  setServoAngle(SERVO9, 10);
  delay(100);
  setServoAngle(SERVO16, 125);
  setServoAngle(SERVO2, 50);
  setServoAngle(SERVO15, 125);
  setServoAngle(SERVO3, 30);
  setServoAngle(SERVO13, 125);
  setServoAngle(SERVO4, 50);
  delay(500);
  setServoAngle(SERVO16, 0);
  setServoAngle(SERVO2, 180);
  delay(500);
  setServoAngle(SERVO16, 125);
  setServoAngle(SERVO2, 50);
  setServoAngle(SERVO14, 0);
  setServoAngle(SERVO1, 180);
  delay(500);
  setServoAngle(SERVO15, 0);
  setServoAngle(SERVO3, 170);
  delay(500);
  setServoAngle(SERVO15, 125);
  setServoAngle(SERVO3, 50);
  setServoAngle(SERVO16, 0);
  setServoAngle(SERVO2, 180);
  delay(500);
  setServoAngle(SERVO9, 10);
  setServoAngle(SERVO13, 0);
  setServoAngle(SERVO4, 180);
  delay(500);
  setServoAngle(SERVO9, 100);
  setServoAngle(SERVO15, 0);
  setServoAngle(SERVO3, 170);
  delay(500);
}

/**
 * Sets servo to specified angle
 * @param servoNum PWM channel number (0-15)
 * @param angle Desired angle (0-180 degrees)
 */
void setServoAngle(uint8_t servoNum, uint8_t angle) {
  uint16_t pulse = map(angle, 0, 180, SERVOMIN, SERVOMAX);
  pwm.setPWM(servoNum, 0, pulse);
}

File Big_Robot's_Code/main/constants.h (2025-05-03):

// constants.h
#ifndef CONSTANTS_H
#define CONSTANTS_H

// Pin definitions for encoders, ultrasonic sensors, and switches
#define ENCA1 2   // Encoder A for Motor 1
#define ENCB1 3   // Encoder B for Motor 1
#define ENCA2 19  // Encoder A for Motor 2
#define ENCB2 18  // Encoder B for Motor 2

#define SWITCH_PIN 8  // Limit switch

#define SIGNAL_PIN 7     // General-purpose signal pin
#define SIGNAL_PIN2 13   // Additional signal pin

#endif

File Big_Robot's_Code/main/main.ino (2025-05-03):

// main.ino
#include <Arduino.h>
#include <Wire.h>
#include <LiquidCrystal_I2C.h>
#include <NewPing.h>
#include <Adafruit_MotorShield.h>
#include <ArduinoLog.h>

#include "constants.h"
#include "motor_control.h"
#include "encoder.h"
#include "pid_control.h"
#include "sequence.h"
#include "signal.h"
#include "globals.h"



// LCD display object
LiquidCrystal_I2C lcd(0x27, 16, 2);

// Pin and state variables
const int REED_PIN = 5;         // Magnetic reed switch pin
bool start = false;             // Start flag
bool endSequenceExecuted = false;    // Completion flag for final sequence
bool initialSequenceCompleted = false;  // Completion flag for initial sequence
unsigned long startTime;        // Timestamp for timing operations

void setup() {
  Serial.begin(9600);
  Log.begin(LOG_LEVEL_VERBOSE, &Serial);
  Log.notice("Robot initialized. Waiting for start signal...");

  AFMS.begin();  // Initialize motor shield

  // Configure pins
  pinMode(ENCA1, INPUT);
  pinMode(ENCB1, INPUT);
  pinMode(ENCA2, INPUT);
  pinMode(ENCB2, INPUT);
  pinMode(SIGNAL_PIN, INPUT);
  pinMode(SIGNAL_PIN2, OUTPUT);
  pinMode(REED_PIN, INPUT_PULLUP);
  pinMode(SWITCH_PIN, INPUT_PULLUP);

  // Initialize LCD
  lcd.init();
  lcd.backlight();
  lcd.setCursor(0, 0);

  // Attach encoder interrupts
  attachInterrupt(digitalPinToInterrupt(ENCA1), readEncoder1, RISING);
  attachInterrupt(digitalPinToInterrupt(ENCA2), readEncoder2, RISING);
}

void loop() {
  int proximity = digitalRead(REED_PIN);  // Check switch

  if (proximity == LOW) {
    Log.notice("Magnet detected. Waiting...");
  } else {
    if (!start) {
      startTime = millis();  // Record start time
      start = true;
      Log.notice("Start signal received. Beginning operations...");
    }

    int switchState = digitalRead(SWITCH_PIN);

    // Execute initial sequence if not done
    if (!initialSequenceCompleted) {
      executeInitialSequence(switchState == LOW);
      initialSequenceCompleted = true;
    }

    // Execute final PID sequence after 95 seconds
    if (!endSequenceExecuted && millis() - startTime >= 95000) {
      Log.notice("95 seconds elapsed. Executing final PID sequence.");
      pid(60);  // Move forward 60 cm
      endSequenceExecuted = true;
      ultrasonicsActive = true;
      Stop();
      while (true);  // Halt after completion
    } else if (!endSequenceExecuted) {
      Stop();  // Ensure motors are stopped
    }
  }
}

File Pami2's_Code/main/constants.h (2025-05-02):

// constants.h
#ifndef CONSTANTS_H
#define CONSTANTS_H

// Infrared sensor for the linefollower
#define RIGHT_SENSOR 4
#define LEFT_SENSOR 5 // Before it was 7 but changed based on Soraya's excel

// Sonar
#define TRIG_PIN_RIGHT 12
#define ECHO_PIN_RIGHT 13
#define TRIG_PIN_LEFT 8
#define ECHO_PIN_LEFT 9
#define MAX_DISTANCE 2 // Maximum distance in cm for measurements

#endif

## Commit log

2025-04-30 Update the pin used section.md
2025-04-30 Add Superstar's pin.md
2025-05-02 attempt to resolve conflict
    [main.ino, servo_controller.cpp, servo_controller.h]
2025-05-02 fix file in folder
    [Code_pami_2.ino, constants.h, globals.cpp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]
2025-05-02 Revert "Merge pull request #5 from Soraya-j/main"
    This reverts commit b9fd7170c9718d1cdd1a7dd4579e6a585c042017, reversing
    changes made to 5f35917a82b7554a1527c80ebec3fae197350e37.
    [main.ino, servo_controller.cpp, servo_controller.h]
2025-05-02 ArduinoLog
    Serialprint -> Log.notice.....
2025-05-04 3D pieces .stl files
    [IR_pami.stl, IR_vertical_superstar.stl, US_Pami.stl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]
